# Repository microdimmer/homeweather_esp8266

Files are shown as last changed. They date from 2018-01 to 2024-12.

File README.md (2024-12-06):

# Arduino esp8266 home weather station

Clock with auto backlight, NTP time-sync, measuring CO2, humidity, temperature, atmospheric pressure and Blynk or Cayenne synchronization.

## Components

* CO2 Sensor MH-Z19
* ESP8266 (NodeMCU ESP12+ based)
* ST7920 128x64 LCD display
* Humidity/Pressure/Temperature BME280
* Photoresistor 5528 LDR
* NPN transistor P2N2222A or similar
* Buttons, resistors, wires, enclosure
### Optional
* TL431 for better display contrast adjust. (attention! need to cut JP3 on display, see photos)

## Photos:
### Version with 3D-printed case and buttons
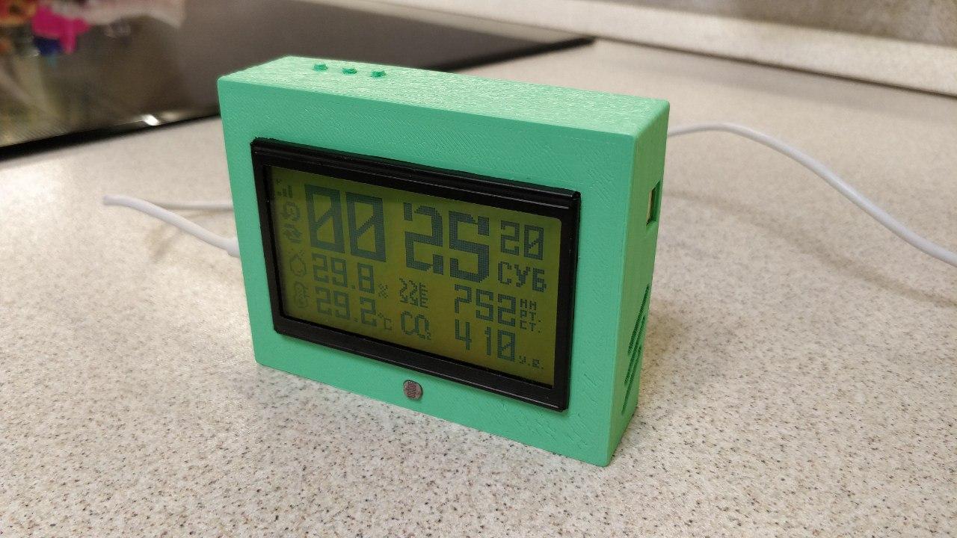
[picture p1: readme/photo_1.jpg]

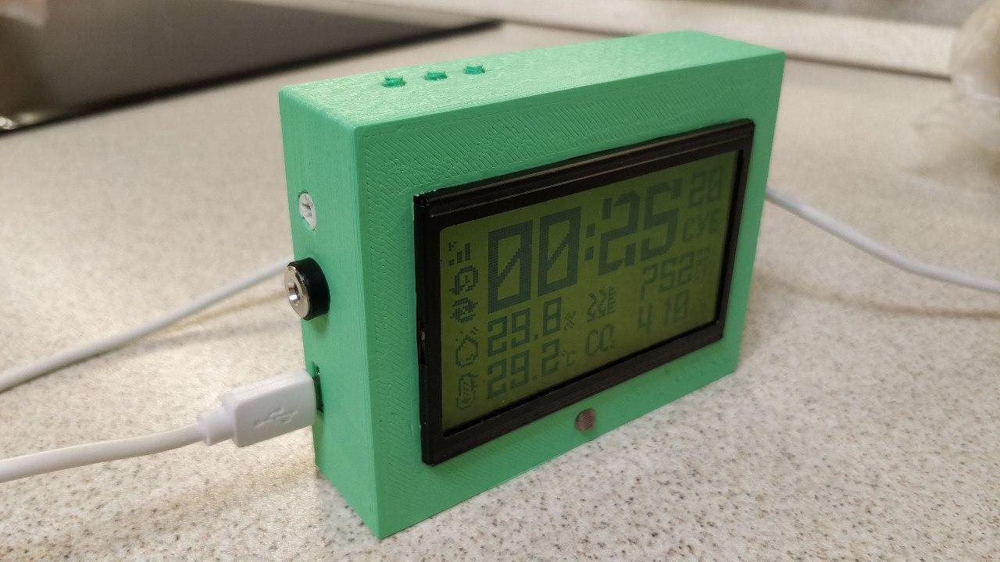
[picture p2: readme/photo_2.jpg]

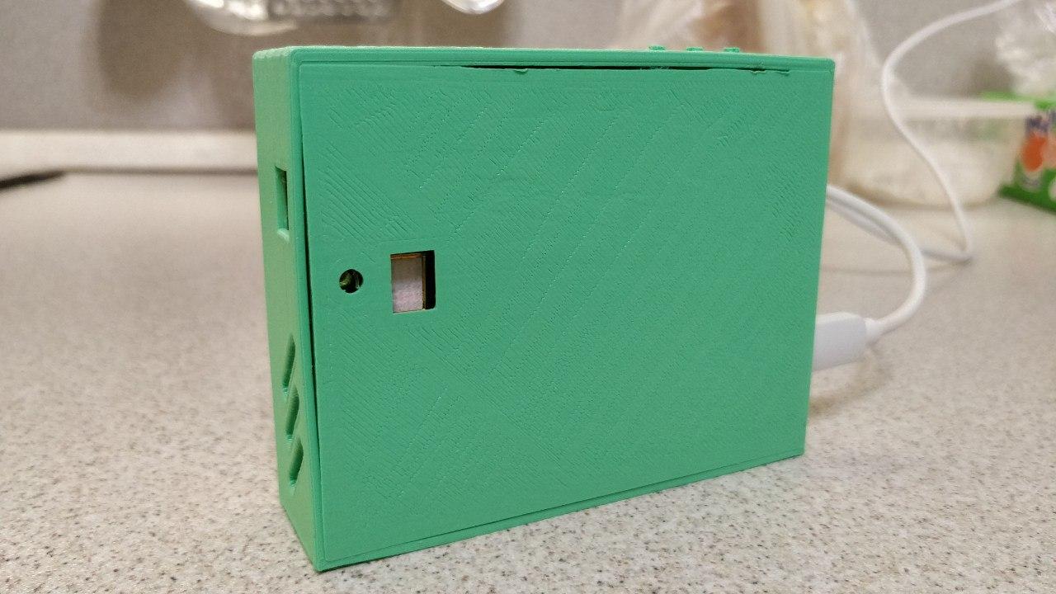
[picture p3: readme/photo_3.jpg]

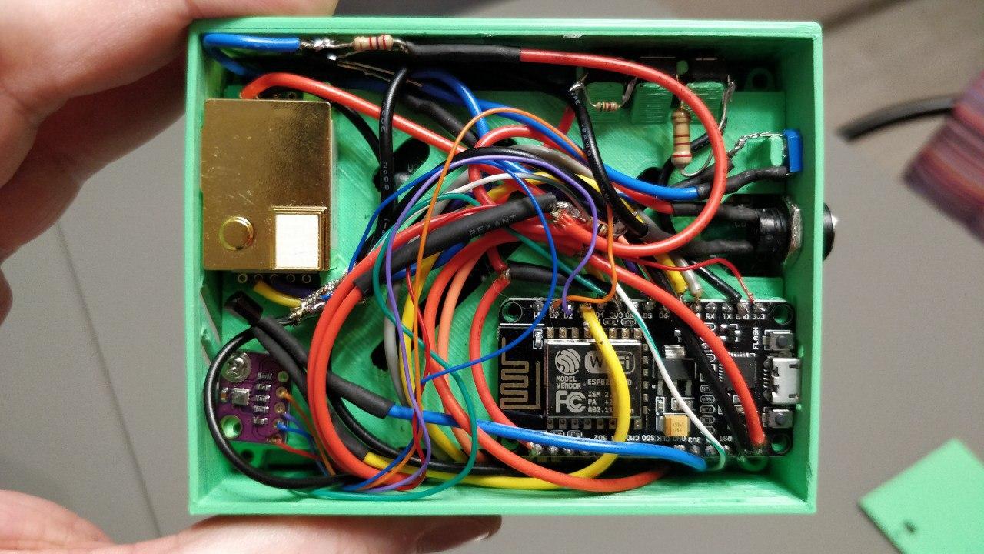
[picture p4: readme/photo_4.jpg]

### Version with purchased case and buttons
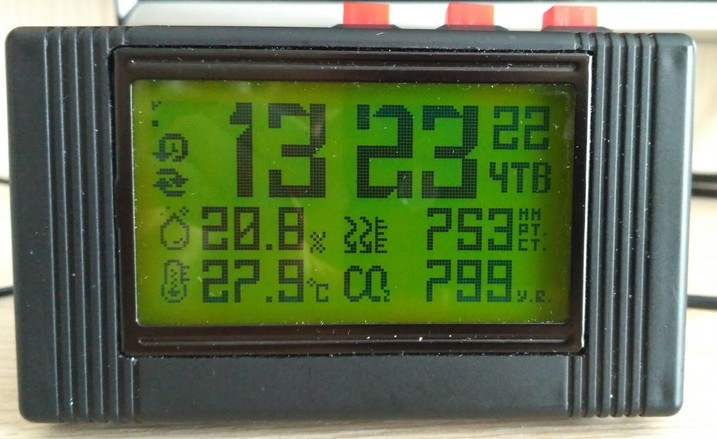
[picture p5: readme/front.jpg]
front_photo

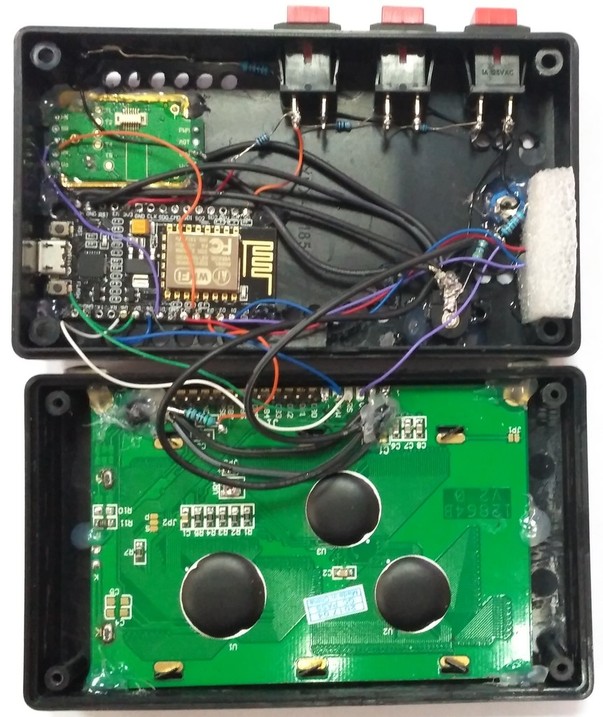
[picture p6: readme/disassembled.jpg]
disassembled_photo

### Version with 3D-printed case and buttons from [ffnull](https://github.com/ffnull)
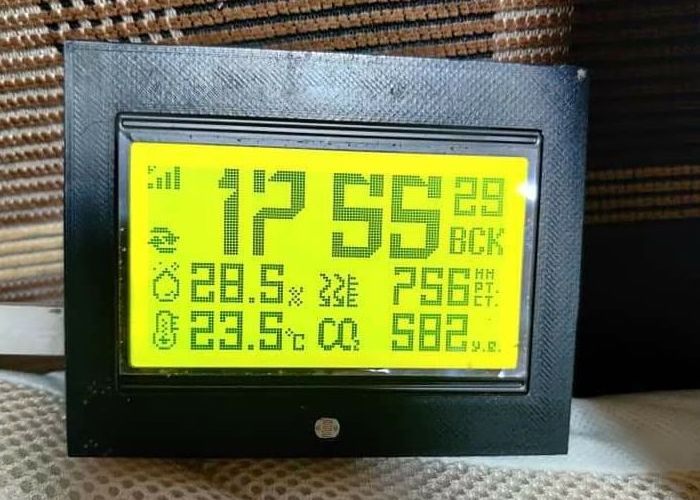
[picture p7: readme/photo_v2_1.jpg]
front_photo

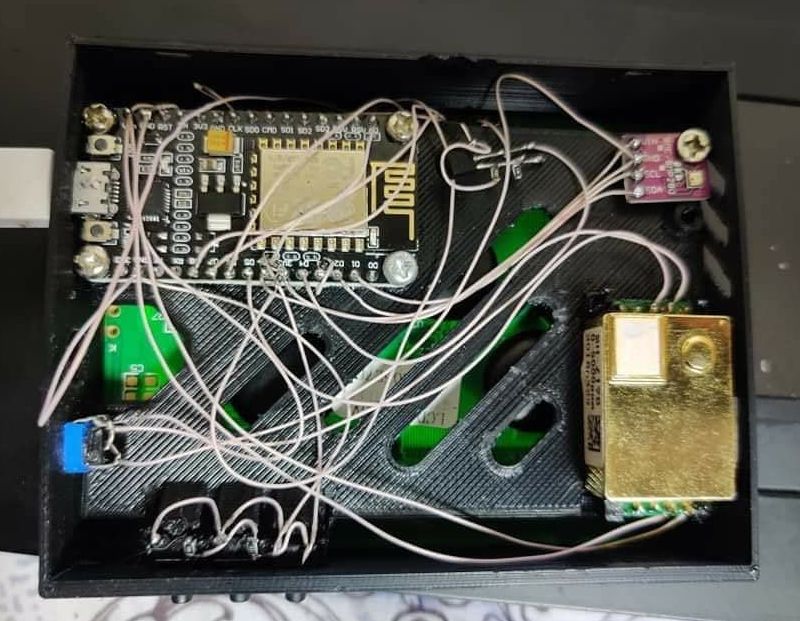
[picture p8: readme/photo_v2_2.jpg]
disassembled_photo


## 3D models
In stl folder

## Blynk and Cayenne:
[Blynk docs](http://docs.blynk.cc/)

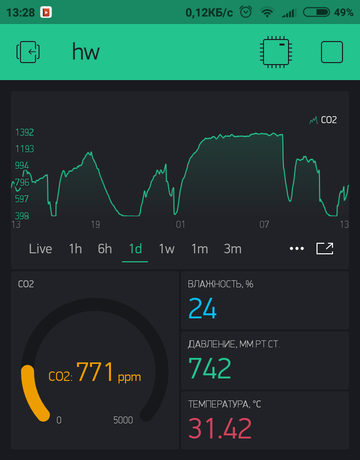
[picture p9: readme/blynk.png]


[Cayenne docs](https://mydevices.com/cayenne/features/api/)

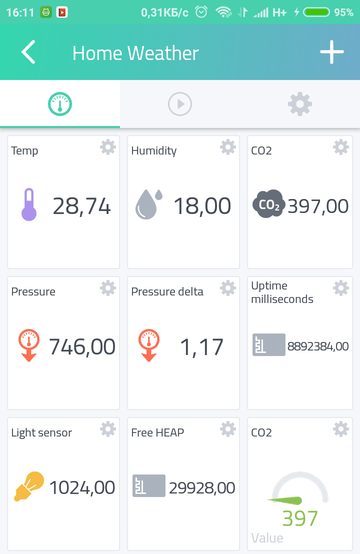
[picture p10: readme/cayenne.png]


Data is bounded to this values:
* v1 - temperature;
* v2 - humidity;
* v4 - atmospheric pressure;
* v5 - CO2 sensor MH-Z19;
* v7 - light sensor;

## Libraries

* [Arduino-esp8266](https://github.com/esp8266/Arduino)
* [Blynk](https://github.com/blynkkk/blynk-library)
* [Cayenne](https://github.com/myDevicesIoT/Cayenne-MQTT-Arduino)
* [u8g2](https://github.com/olikraus/u8g2)
* [Adafruit_BME280_Library](https://github.com/adafruit/Adafruit_BME280_Library)
* [WiFiManager](https://github.com/tzapu/WiFiManager)
* [ArduinoJson](https://github.com/bblanchon/ArduinoJson)
* [AsyncPing](https://github.com/akaJes/AsyncPing)
* [SimpleTimer](http://playground.arduino.cc/Code/SimpleTimer)
* [TimeLibrary](https://github.com/PaulStoffregen/Time)

## Wiring:
```
ST7920
RS - D8
R/W - D7
E - D6
backlight - D3

mh-z19
RX - D4
TX - D5

BME-280
SDA - D1
SCL - D2
VCC - 3V3
```

## Scheme:
### With TL431:
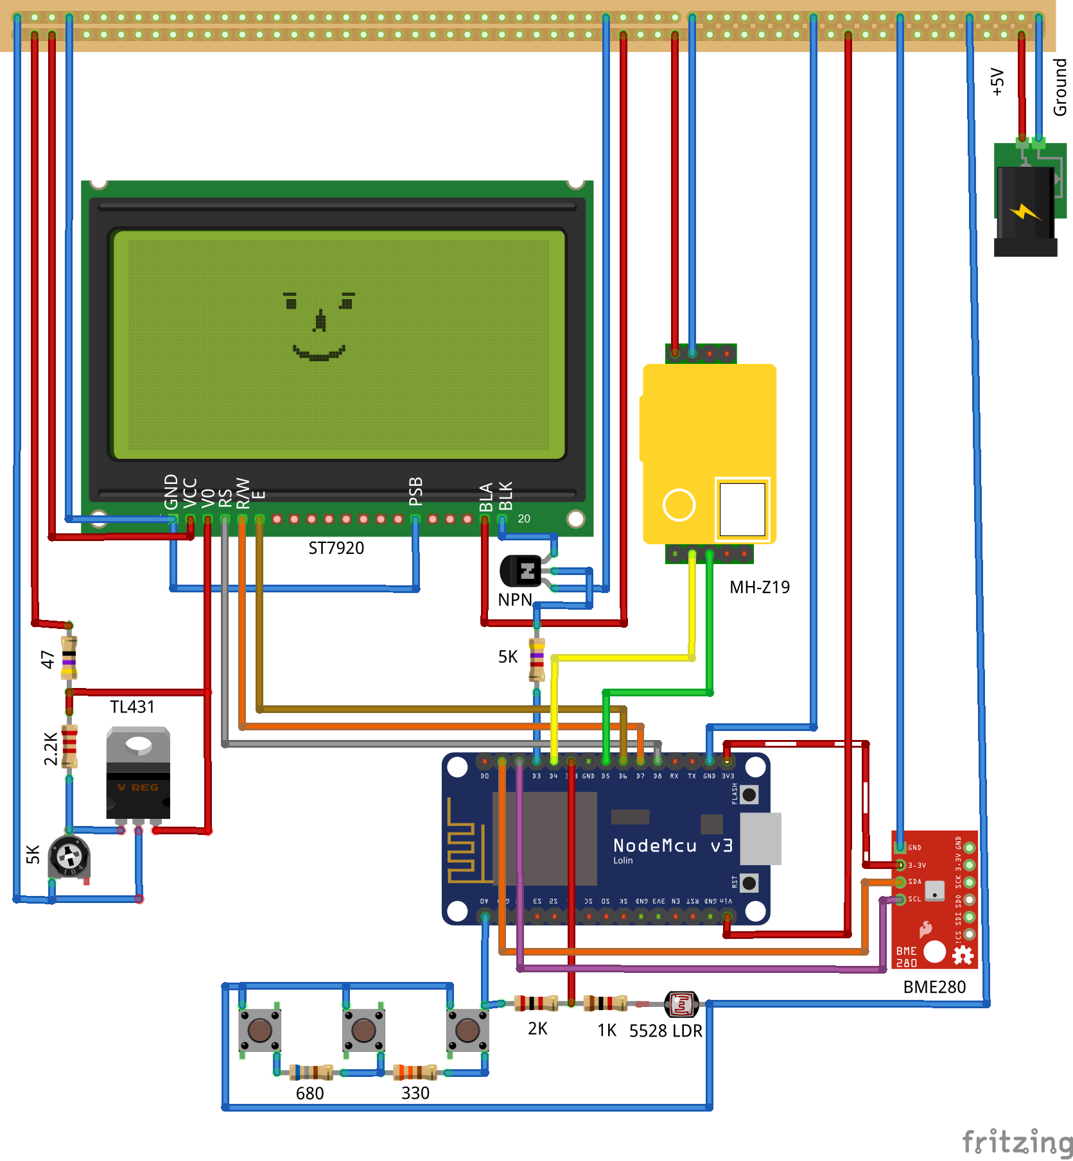
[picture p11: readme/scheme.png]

### Without TL431:
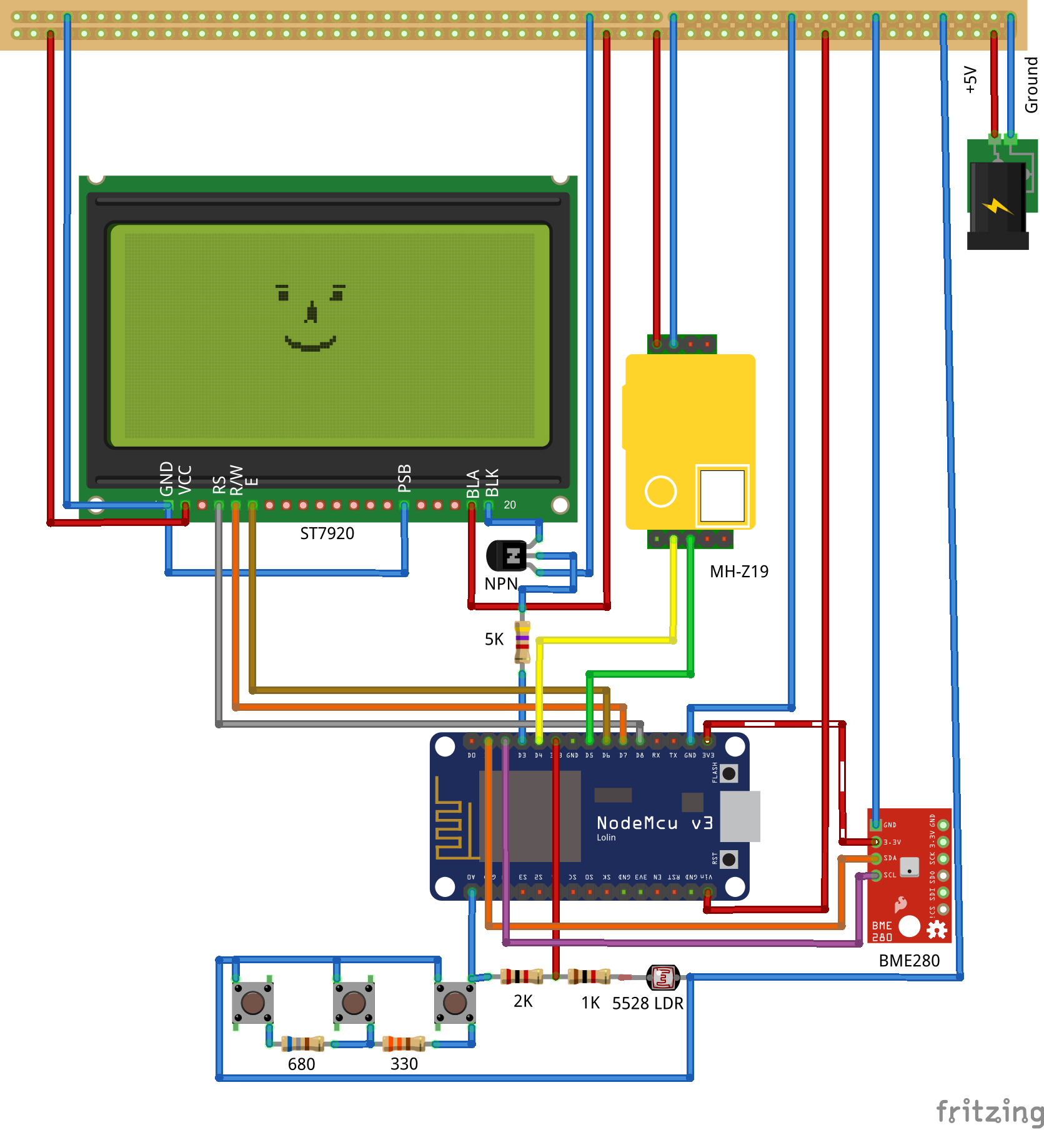
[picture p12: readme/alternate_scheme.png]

### Jumper JP3:
Attention! JP3 need to be cut to use TL431. TL431 is using for better display contrast adjust.
#### Cut:
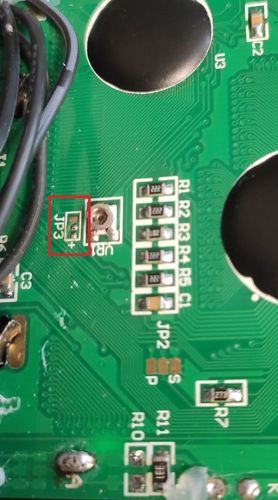
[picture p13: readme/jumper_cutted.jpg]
jumper_cut

#### Uncut:
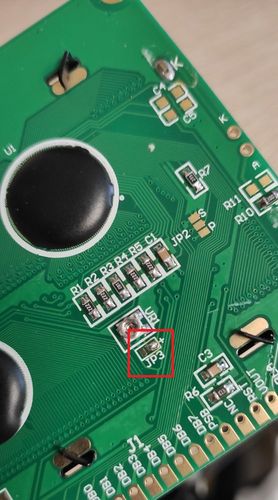
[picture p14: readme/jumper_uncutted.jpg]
jumper_uncut


## Known issues:

* Temperature measurements seems to be higher due to heat from ESP8266
* ST7920 plate need to be cut to fit enclosure
* Can't connect to my old ASUS WL-500gP V2

# Russian:
Часы с синхронизацией времени по WI-FI, функцией измерения CO2, температуры, влажности, давления. Также есть автоматическое изменение подсветки в зависимости от освещения.
Часы синхронизируются по NTP протоколу через WI-FI. Данные датчиков передаются на сервер Blynk или Cayenne.

## Компоненты

* Датчик CO2 MH-Z19
* NodeMCU v2
* ST7920 128x64 LCD-дисплей
* датчик давления/влажности/температуры BME280
* фоторезистор 5528 LDR
* NPN тразистор P2N2222A или похожий
* кнопки, резисторы, провода, корпус
### Опционально
* TL431 стабилизатор напряжения, используется для более удобной настройки контраста дисплея, можно им пренебречь. (внимание! если хотите использовать стабилизатор, нужно распаять джампер JP3 на дисплее, см. фото)

## Библиотеки

* [Arduino-esp8266](https://github.com/esp8266/Arduino)
* [Blynk](https://github.com/blynkkk/blynk-library)
* [Cayenne](https://github.com/myDevicesIoT/Cayenne-MQTT-Arduino)
* [u8g2](https://github.com/olikraus/u8g2)
* [Adafruit_BME280_Library](https://github.com/adafruit/Adafruit_BME280_Library)
* [WiFiManager](https://github.com/tzapu/WiFiManager)
* [ArduinoJson](https://github.com/bblanchon/ArduinoJson)
* [AsyncPing](https://github.com/akaJes/AsyncPing)
* [SimpleTimer](http://playground.arduino.cc/Code/SimpleTimer)
* [TimeLibrary](https://github.com/PaulStoffregen/Time)

## Подключение:
```
дисплей 12864 
RS - D8
R/W - D7
E - D6
катод подсветки - D3

датчик mh-z19
RX - D4
TX - D5

датчик BME-280
SDA - D1
SCL - D2
VCC - 3V3
```
## Известные проблемы:

* ESP8266 греется и вносит погрешность в показания температуры, пока изолировал датчик BME-280 вспененным полиэтиленом
* Пришлось немного подрезать плату дисплея ST7920 сверху, не входила по высоте
* Не удалось подключить к роутеру ASUS WL-500gP V2 (видимо нужно разбираться с типом WI-FI сети на роутере)

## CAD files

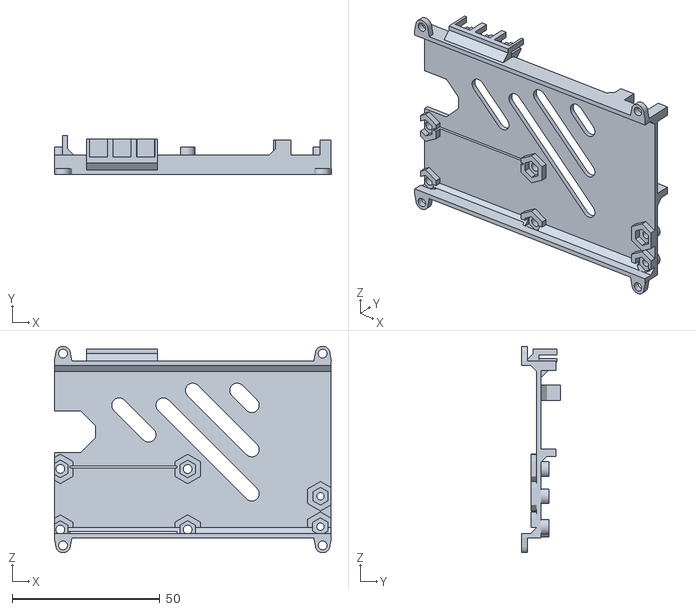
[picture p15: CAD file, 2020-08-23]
stl/mount.stl
93.9 x 13.1 x 70.0

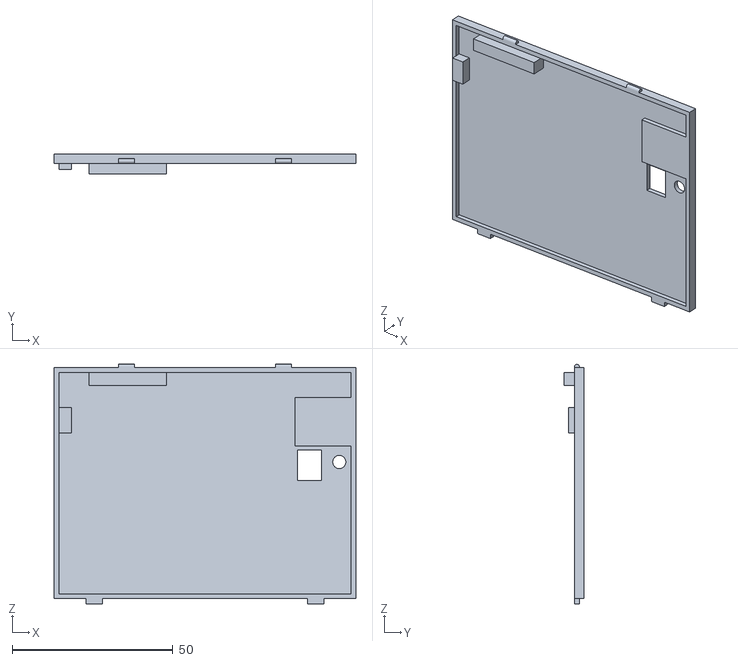
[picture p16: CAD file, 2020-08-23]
stl/back_cover.stl
93.8 x 6.30 x 74.4

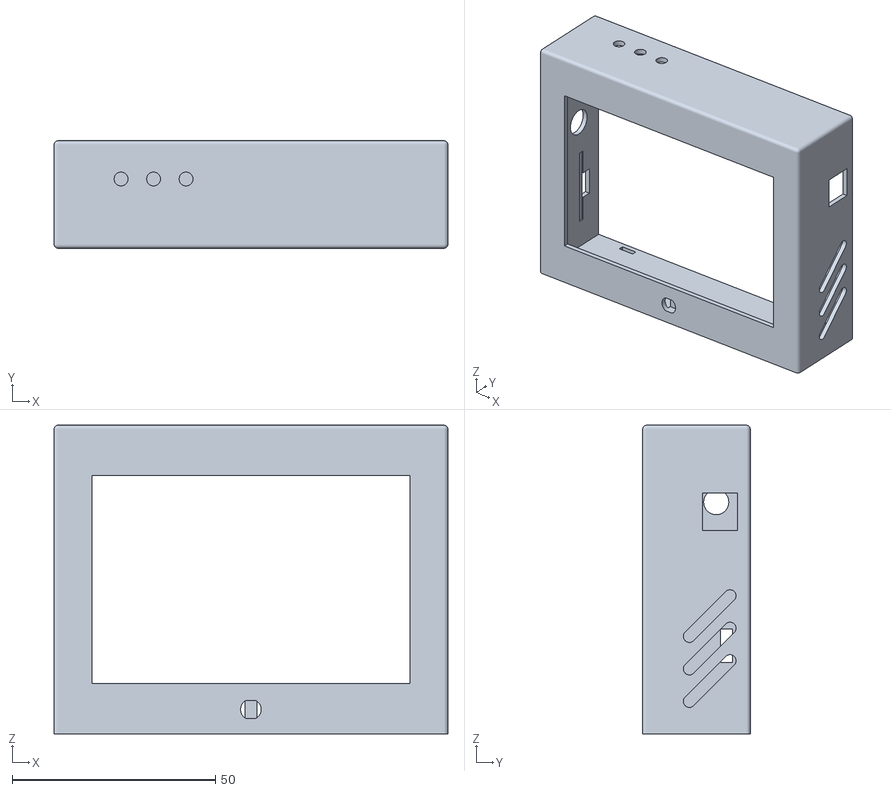
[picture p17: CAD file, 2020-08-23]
stl/case.stl
97.0 x 26.5 x 76.0

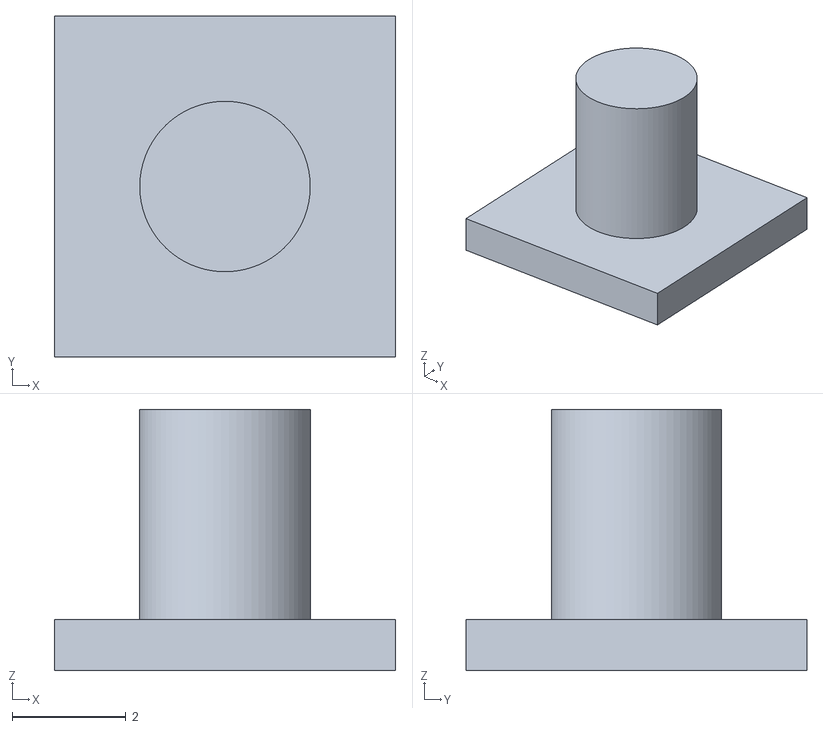
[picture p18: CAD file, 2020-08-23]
stl/pressBtn1.stl
6.00 x 6.00 x 4.60

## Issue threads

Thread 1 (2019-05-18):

TL431

sergeyvasilievich, 2019-05-18:
А для чего в схеме TL431

microdimmer, 2019-11-19:
Устанавливает постоянное напряжение на вход настройки контрастности дисплея. Так как прибор работает от почти любого блока питания на 5 В, то, из-за плавающего напряжения, при смене блока питания приходилось постоянно подстраивать контрастность дисплея.

Closed 2019-11-19.

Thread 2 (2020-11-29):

Вопросы

ffnull, 2020-11-29:
Здраствуйте!
Напечатал все детали, собрал. Но
Ни в какую не работает подсветка по датчику. В дебаге постоянно 1024.
В вариации с TL431 в схеме, похоже что ошибка - не работает от слова совсем. Временно сделал просто через резистор 5кОм
Можно исходники корпуса? Так-как были другие кнопки и датчик CO2 и пришлось колхозить.
Кнопки дают мисклики.
И главное: Спасибо за шикарный проект!

ffnull, 2020-11-29:
Еще вопрос о калибровке CO2. Возможно добавить параметр отключения автокалибровки и включение калибровки по 400ppm?

ffnull, 2020-12-20:
Автор, вы жив?

microdimmer, 2021-01-23:
Добавил 3d-модель в паку step. По второму вопросу - это для чего?

microdimmer, 2021-01-23:
Странно, но не приходят уведомления на почту, только сейчас увидел.

ffnull, 2021-01-23:
Спасибо за исходники. Пробую переписать под MQTT. Так-же добавил конденсатор на 1000Мфх16В в цепь 5В для стабилизации моргания подсветки во время включения нагрева датчика CO2. Единственное не знаю что делать с датчиком света, для автояркости. Ну и контрастность через TL431  у меня не заработала от слова совсем. Трижды перепроверил.

microdimmer, 2021-01-23:
Если что можно списаться https://t.me/microdimmer

Closed 2021-11-22.

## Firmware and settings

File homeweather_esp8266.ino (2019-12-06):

#include <FS.h>
#include <Arduino.h>
#include <SPI.h>
#include <Wire.h>
#include <SoftwareSerial.h>
#include <ESP8266WiFi.h> // Wifi Manager https://github.com/esp8266/Arduino
#include <ESP8266WebServer.h>
#include <WiFiManager.h> //https://github.com/tzapu/WiFiManager
#include <DNSServer.h>
#include <ESP8266HTTPClient.h> // HTTP requests
#include <WiFiUdp.h> //for NTP
#include <AsyncPing.h> //async pinger
#include <TimeLib.h> //timekeeping
#include <ESP8266httpUpdate.h> //OTA updates
#include <ArduinoJson.h> //https://github.com/bblanchon/ArduinoJson
#include <SimpleTimer.h> // Handy timers
#include <Adafruit_Sensor.h>
#include <Adafruit_BME280.h>
#include <U8g2lib.h>

//Preferences
// #define DEBUG //uncomment for debug messages
// #define BLYNK //uncomment for use Blynk, otherwise use Cayenne data aggregator

#ifdef BLYNK
#include <BlynkSimpleEsp8266.h> //Blynk
#else
#include <CayenneMQTTESP8266.h> //Cayenne
#endif

const uint16_t WIFI_TIMEOUT = 180;
const char * SSID = "YourHomeWeather"; // Network credentials
//String pass {"YHWBopka"}; // Wi-Fi AP password
// GPIO Defines
const uint8_t I2C_SDA = 5; // D1, SDA pin, GPIO5 for BME280
const uint8_t I2C_SCL = 4; // D2, SCL pin, GPIO4 for BME280
const uint8_t PWM_PIN = 0; //D3, GPIO0, for ST7920
const uint8_t SCLK_PIN = 12; // D6, E pin, GPIO12, for ST7920 acts like CLK (clock) input pin
const uint8_t RW_PIN = 13; // D7, R/W pin, GPIO13, for ST7920 acts like DATA pin
const uint8_t RS_PIN = 15; // D8, RS pin, GPIO15, for ST7920 acts like CS (Chip Select) pin
const uint8_t TX_PIN = 2; //D4, RX pin, GPIO2, for mz-h19
const uint8_t RX_PIN = 14; //D5, TX pin, GPIO14, for mz-h19

//display ST7920
U8G2_ST7920_128X64_F_SW_SPI u8g2(U8G2_R0,/*display-clock E,SCLK;esp-GPIO12,D6*/SCLK_PIN,/*display-data R/W;esp-GPIO13,D7*/RW_PIN,/*display-RS;esp-GPIO15,D8*/RS_PIN);
// Humidity/Temperature/Pressure/CO2
Adafruit_BME280 bme;
SoftwareSerial swSer(RX_PIN, TX_PIN);// CO2 SERIAL
//SoftwareSerial swSer(RX_PIN, TX_PIN, false, 256);// CO2 SERIAL
byte cmd[9] = {0xFF, 0x01, 0x86, 0x00, 0x00, 0x00, 0x00, 0x00, 0x79};
unsigned char response[7];
#ifdef BLYNK
// Blynk token
char blynk_token[33] {"7ca0a9293079453499aa5453883510cf"};
char blynk_server[64] {"blynk-cloud.com"};
const uint16_t blynk_port {8442};
#else
// Cyenne credentials
char cayenne_username[] = "edc8aad0-d07d-11e7-8123-07faebe02555";
char cayenne_password[] = "3924eb177886b6280ee0b13b0045d2a5a7e66216";
char cayenne_clientID[] = "2dd4dd50-479e-11e8-bf56-db14f0c2b326";
#endif
// Device Id
char device_id[17] = "Home Weather";
const char fw_ver[17] = "0.1.22";
// Handy timer
SimpleTimer timer;
// Setup Wifi connection
WiFiManager wifiManager;

//sensors data
int16_t t { -100};
int16_t p { -1};
int16_t h { -1};
int co2 {0};
float tf {0};
float pf {0};
float hf {0};
uint16_t light;
uint16_t adc_data;
uint32_t uptime = 0;
//buttons
const uint8_t NUM_KEYS = 3;
int adc_key_val[NUM_KEYS] = {100, 200, 360};
uint32_t lastDebounceTime = 0;
uint16_t debounceTime = 250;
uint32_t lastIdleTimeMenu = 0;
uint32_t idleTimeMenu = 180000; // menu idle time 3 min
// Math data for pressure calculating, see http://bit.ly/1EXW1I9 http://bit.ly/1DIbvyj
const uint8_t P_LEN = 4;
float p_array[P_LEN];
float delta;
//flags
volatile bool connectedInetFlag = false; //flag if connected
bool timeSyncFlag = false;
bool cloudSyncFlag = false;
#ifndef BLYNK
bool CayenneConnectedFlag = false;
#endif
bool shouldSaveConfig = false; //flag for saving data if connectio estalished
//menu
bool timeSetFlag = false; //TODO del flags
bool timeSetMinFlag = false;
bool timeSetHourFlag = false;
bool timeSetTimeZoneFlag = false;
bool timeSetDayFlag = false;
bool timeSetMonthFlag = false;
bool timeSetYearFlag = false;
bool backlightSetFlag = false;
bool backlightSetLEDFlag = false;
bool backlightSetMinFlag = false;
bool backlightSetMaxFlag = false;
bool backlightSetThresoldFlag = false;

bool menuFlag = false;
int8_t curMenuItem = 3;
int8_t menuItemsCount = 4;

int32_t wifiRSSI = 0;

const uint16_t pwm_light[14] = {0, 0, 2, 4, 8, 16, 32, 64, 96, 128, 192, 256, 320, 384};
int8_t light_mode = 0;
int8_t light_auto_min = 2; //default min backlight
int8_t light_auto_max = 11; //default max backlight
uint16_t light_auto_thresold = 1023; //default thresold
uint32_t lightLastHysteresisTimeMin = 0;
uint32_t lightLastHysteresisTimeMax = 0;
uint16_t lightHysteresisTime = 2500; //2.5 secs hysteresis for light sensor

AsyncPing aping;

WiFiUDP Udp;
const char* ntpServerName = "0.ru.pool.ntp.org"; //NTP server (ntp2.stratum2.ru,ntp1.vniiftri.ru)
IPAddress ntpServerIP;
#ifdef BLYNK
IPAddress pingServerIP(139, 59, 206, 133); //blynk serv for ping
#endif
unsigned int localPort = 4567;  // local port to listen for UDP packets
const int NTP_PACKET_SIZE = 48; // NTP time is in the first 48 bytes of message
byte packetBuffer[NTP_PACKET_SIZE]; //buffer to hold incoming & outgoing packets
const uint16_t timeZonesArr[11] = {2, 3, 4, 5, 6, 7, 8, 9, 10, 11, 12};
int8_t timeZone = 3;         // default timezone UTC +5

String timestring = "";//TODO

#include "graphics.h"

#ifdef DEBUG
#define PRINTLNF(s)   { Serial.println(F(s)); }
#define PRINTLN(s,v)  { Serial.print(F(s)); Serial.println(v); }
#else
#define PRINTLNF(s)
#define PRINTLN(s,v)
#endif


time_t getNtpTime() {
  while (Udp.parsePacket() > 0) ; // discard any previously received packets
  PRINTLNF("Transmit NTP Request");
  #ifdef BLYNK
  ntpServerIP = pingServerIP;
  #else
  WiFi.hostByName(ntpServerName, ntpServerIP); //get IP address
  #endif
  sendNTPpacket(ntpServerIP);
  uint32_t beginWait = millis();
  while (millis() - beginWait < 1500) {
    int size = Udp.parsePacket();
    if (size >= NTP_PACKET_SIZE) {
      PRINTLNF("Receive NTP Response");
      Udp.read(packetBuffer, NTP_PACKET_SIZE);  // read packet into the buffer
      unsigned long secsSince1900;
      // convert four bytes starting at location 40 to a long integer
      secsSince1900 =  (unsigned long)packetBuffer[40] << 24;
      secsSince1900 |= (unsigned long)packetBuffer[41] << 16;
      secsSince1900 |= (unsigned long)packetBuffer[42] << 8;
      secsSince1900 |= (unsigned long)packetBuffer[43];
      timeSyncFlag = 1;
      return secsSince1900 - 2208988800UL + timeZonesArr[timeZone] * SECS_PER_HOUR;
    }
  }
  PRINTLNF("No NTP Response :-(");
  timeSyncFlag = 0;
  return 0; // return 0 if unable to get the time
}

void sendNTPpacket(IPAddress &address) { // send an NTP request to the time server at the given address
  // set all bytes in the buffer to 0
  memset(packetBuffer, 0, NTP_PACKET_SIZE);
  // Initialize values needed to form NTP request
  packetBuffer[0] = 0b11100011;   // LI, Version, Mode
  packetBuffer[1] = 0;     // Stratum, or type of clock
  packetBuffer[2] = 6;     // Polling Interval
  packetBuffer[3] = 0xEC;  // Peer Clock Precision
  // 8 bytes of zero for Root Delay & Root Dispersion
  packetBuffer[12]  = 49;
  packetBuffer[13]  = 0x4E;
  packetBuffer[14]  = 49;
  packetBuffer[15]  = 52;
  // all NTP fields have been given values, now
  // you can send a packet requesting a timestamp:
  Udp.beginPacket(address, 123); //NTP requests are to port 123
  Udp.write(packetBuffer, NTP_PACKET_SIZE);
  Udp.endPacket();
}

void syncTime() {
  setTime(getNtpTime());
  #ifdef DEBUG
    timeStatus_t t_status = timeStatus();
    if (t_status == timeNotSet) {
      PRINTLNF("Time never been synced");
    }  
    else if (t_status == timeNeedsSync) {
      PRINTLNF("Time is need to sync");
    }  
    else if (t_status == timeSet) {
      PRINTLNF("Time is synced");
    }
  #endif    
}

String weekdayRus(byte weekday) {
  switch (weekday) {
    case 2:
      return "PON";
    case 3:
      return "VTR";
    case 4:
      return "SRD";
    case 5:
      return "CTV";
    case 6:
      return "PTN";
    case 7:
      return "SYB";
    case 1:
      return "VSK";
  }
  return "0";
}

void drawSignalQuality(uint8_t x, uint8_t y) {
  if (!connectedInetFlag) {
    u8g2.drawLine(x, y, x + 2, y + 2);
    u8g2.drawLine(x, y + 2, x + 2, y);
  }
  else {
    u8g2.drawLine(x, y + 2, x + 2, y);
    u8g2.drawLine(x, y, x, y + 2);
  }
  y = y + 6;
  if (wifiRSSI >= -90)
    u8g2.drawFrame(x, y, x + 2, y - 4);
  if (wifiRSSI >= -85)
    u8g2.drawFrame(x + 3, y - 2, x + 2, y - 2);
  if (wifiRSSI >= -75)
    u8g2.drawFrame(x + 6, y - 4, x + 2, y);
  if (wifiRSSI >= -65)
    u8g2.drawFrame(x + 9, y - 6, x + 2, y + 2);
}

const char *GetStringLine(uint8_t line_idx, const char *str ) { //Assumes strings, separated by '\n' in "str". Returns the string at index "line_idx". First strng has line_idx = 0
  char e;
  uint8_t line_cnt = 1;

  if ( line_idx == 0 )
    return str;

  for (;;)
  {
    e = *str;
    if ( e == '\0' )
      break;
    str++;
    if ( e == '\n' )
    {
      if ( line_cnt == line_idx )
        return str;
      line_cnt++;
    }
  }
  return NULL;  /* line not found */
}

const char* printDigits(uint16_t digits, bool blinking = false, bool leadingZero = true) { //prints preceding colon and leading 0, blinking
  timestring = String(digits);
  if (blinking && ((millis() / 500 % 2) == 0))
    return "";
  if (digits < 10 && leadingZero)
    timestring = "0" + String(digits);

  return timestring.c_str();
}

void drawMainScreen() {
  u8g2.clearBuffer();
  u8g2.setFont(custom_font_14);
  if (timeSetFlag) {
    u8g2.drawStr(15, 14, printDigits(hour(), timeSetHourFlag));
    u8g2.drawStr(35, 14, ":");
    u8g2.drawStr(39, 14, printDigits(minute(), timeSetMinFlag));
    u8g2.setFont(custom_font_7);
    u8g2.drawStr(62, 10, "utc");
    u8g2.setFont(custom_font_14);
    u8g2.drawStr(76, 14, "+");
    u8g2.drawStr(84, 14, printDigits(timeZonesArr[timeZone], timeSetTimeZoneFlag, false));
    u8g2.drawStr(15, 30, printDigits(day(), timeSetDayFlag));
    u8g2.drawStr(35, 30, ".");
    u8g2.drawStr(39, 30, printDigits(month(), timeSetMonthFlag));
    u8g2.drawStr(59, 30, ".");
    u8g2.drawStr(64, 30, printDigits(year(), timeSetYearFlag));
  }
  else if (backlightSetFlag) {
    u8g2.setFont(custom_font_7);
    u8g2.drawStr(17, 14, "led:");
    if (light_mode == 0) {
      u8g2.drawStr(62, 14, "min:");
      u8g2.drawStr(13, 24, "thre");
      u8g2.drawStr(13, 30, "sold:");
      u8g2.drawStr(62, 30, "max:");
      u8g2.setFont(u8g2_font_7x13_mf);
      u8g2.drawStr(32, 14, "auto");
      u8g2.setFont(custom_font_14);
      u8g2.drawStr(32, 30, printDigits(light_auto_thresold / 10, backlightSetThresoldFlag, false));
      u8g2.drawStr(77, 14, printDigits(light_auto_min, backlightSetMinFlag, false));
      u8g2.drawStr(77, 30, printDigits(light_auto_max, backlightSetMaxFlag, false));
    }
    else if (light_mode == 1) {
      u8g2.setFont(u8g2_font_7x13_mf);
      u8g2.drawStr(32, 14, "off");
    }
    else {
      u8g2.setFont(custom_font_14);
      u8g2.drawStr(32, 14, printDigits(light_mode, backlightSetFlag, false));
    }
  }
  else { //draw time
    u8g2.setFont(custom_font30);
    u8g2.drawStr(15, 30 , printDigits(hour()));
    if ((millis() / 1000) % 2) u8g2.drawStr(57, 30 , ":");
    u8g2.drawStr(64, 30 , printDigits(minute()));
  }

  if (WiFi.status() == WL_CONNECTED) {
    drawSignalQuality(0, 0);
  }
  if (timeSyncFlag) {
    u8g2.drawXBMP(0, 10, 11, 9, clock_bitmap);
  }
  if (cloudSyncFlag) {
    u8g2.drawXBMP(0, 21, 11, 9, sync_bitmap);
  }

  u8g2.setFont(rus_font);
  u8g2.drawStr(107, 28, weekdayRus(weekday()).c_str());

  u8g2.setFont(custom_font_14);
  u8g2.drawStr(108, 14 , printDigits(day()));

  //CO2
  String co2String = String(co2);
  u8g2.drawXBMP(60, 52, 15, 12, co_bitmap);
  u8g2.drawStr(117 - (co2String.length() * 10), 64 , co2String.c_str());
  // Temp, Humidity, Pressure
  String tfString = String(tf, 1);
  u8g2.drawXBMP(2, 50, 10, 14, temp_bitmap);
  u8g2.drawStr(55 - (tfString.length() * 10), 64, tfString.c_str());

  String hfString = String(hf, 1);
  u8g2.drawXBMP(2, 33, 10, 14, humid_bitmap);
  u8g2.drawStr(55 - (hfString.length() * 10), 47, hfString.c_str());

  u8g2.drawXBMP(60, 36, 14, 12, p_bitmap);

  if (delta > 2) {
    u8g2.drawGlyph(76, 47, 30); //big arrow up
  }
  else if (delta > 1) {
    u8g2.drawGlyph(76, 47, 28); //small arrow up
  }
  else if (delta < -2) {
    u8g2.drawGlyph(76, 47, 31); //big arrow down
  }
  else if (delta < -1) {
    u8g2.drawGlyph(76, 47, 29); //small arrow down
  }

  u8g2.drawStr(87, 47, String(p).c_str());

  u8g2.setFont(custom_font_7);
  u8g2.drawGlyph(48, 64, 0xb0); //degree sign
  u8g2.drawStr(51, 64, "C");
  u8g2.drawGlyph(49, 48, 0x25); //percent
  u8g2.drawStr(117, 64 , "y.e.");
  u8g2.drawStr(117, 37 , "mm");
  u8g2.drawStr(117, 42 , "pt.");
  u8g2.drawStr(117, 47 , "ct.");

  u8g2.sendBuffer();
}

void drawMenu(const char *title, uint8_t start_pos, const char *line) {
  if ((millis() - lastIdleTimeMenu) > idleTimeMenu) {
    menuFlag = false;
    return;
  }

  u8g2.clearBuffer();
  byte x {0}; byte y {0};

  u8g2.setFont(u8g2_font_7x13_mf);

  x = (128 - u8g2.getStrWidth(title)) / 2;
  y = u8g2.getAscent() - u8g2.getDescent() - 2;
  u8g2.drawStr(x, y, title);
  y++;
  u8g2.drawHLine(0, y, 127);

  for (byte  i = 0; i < menuItemsCount; i++) {
    const char *msg = GetStringLine(i, line);
    if (i == start_pos) {
      u8g2.drawBox(0, y + 2, 127, u8g2.getAscent() - u8g2.getDescent() + 2);
      u8g2.setDrawColor(0);
    }
    else
      u8g2.setDrawColor(1);
    x = (128 - u8g2.getStrWidth(msg)) / 2;
    y = y + 2 + u8g2.getAscent() - u8g2.getDescent();
    u8g2.drawStr(x, y, msg);
  }
  u8g2.setDrawColor(1);
  u8g2.sendBuffer();
}

void drawBoot(String msg = "loading...") {
  u8g2.clearBuffer();
  u8g2.setFont(u8g2_font_7x13_mf);
  byte x {0}; byte y {0};
  x = (128 - u8g2.getStrWidth(msg.c_str())) / 2;
  y = 32 + u8g2.getAscent() / 2;
  u8g2.drawStr(x, y, msg.c_str());
  u8g2.sendBuffer();
}

void drawConnectionDetails(String ssid, String mins, String url) {
  String msg {""};
  u8g2.clearBuffer();
  byte x {0}; byte y {0};

  msg = "Connect to WiFi:";
  u8g2.setFont(u8g2_font_7x13_mf);
  x = (128 - u8g2.getStrWidth(msg.c_str())) / 2;
  y = u8g2.getAscent() - u8g2.getDescent();
  u8g2.drawStr(x, y, msg.c_str());

  x = (128 - u8g2.getStrWidth(msg.c_str())) / 2;
  y = y + 1 + u8g2.getAscent() - u8g2.getDescent();
  u8g2.drawStr(x, y, ssid.c_str());

  msg = "waiting for " + mins;
  x = (128 - u8g2.getStrWidth(msg.c_str())) / 2;
  y = y + 1 + u8g2.getAscent() - u8g2.getDescent();
  u8g2.drawStr(x, y, msg.c_str());

  msg = "Open browser:";
  x = (128 - u8g2.getStrWidth(msg.c_str())) / 2;
  y = y + 1 + u8g2.getAscent() - u8g2.getDescent();
  u8g2.drawStr(x, y, msg.c_str());

  x = (128 - u8g2.getStrWidth(url.c_str())) / 2;
  y = y + 1 + u8g2.getAscent() - u8g2.getDescent();
  u8g2.drawStr(x, y, url.c_str());

  u8g2.sendBuffer();
}

void saveConfigCallback() { //callback notifying when need to save config
  PRINTLNF("Should save config");
  shouldSaveConfig = true;
}

void factoryReset() {
  PRINTLNF("Resetting to factory settings");
  wifiManager.resetSettings();
  SPIFFS.format();
  ESP.reset();
}

void readCO2() {
  bool header_found {false};

  swSer.write(cmd, 9);
  memset(response, 0, 7);

  // Looking for packet start
  while (swSer.available() && (!header_found)) {
    if (swSer.read() == 0xff ) {
      if (swSer.read() == 0x86 ) header_found = true;
    }
  }

  if (header_found) {
    swSer.readBytes(response, 7);

    byte crc = 0x86;
    for (byte i = 0; i < 6; i++) {
      crc += response[i];
    }
    crc = 0xff - crc;
    crc++;

    if ( !(response[6] == crc) ) {
      PRINTLN("CO2: CRC error: ", String(crc) + " / " + String(response[6]));
    } 
    else {
      unsigned int responseHigh = (unsigned int) response[0];
      unsigned int responseLow = (unsigned int) response[1];
      unsigned int ppm = (256 * responseHigh) + responseLow;
      co2 = ppm;
      PRINTLN("CO2:",co2);
    }
  } else {
    PRINTLNF("CO2: Header not found");
  }
}

void readMeasurements() {
  tf = bme.readTemperature(); //Temperature
  t = static_cast<int>(tf);
  hf = bme.readHumidity(); //Humidity
  h = static_cast<int>(hf);
  pf = bme.readPressure() * 760.0 / 101325; //Pressure (in mmHg)
  p = static_cast<int>(floor(pf + 0.5));
  readCO2();// CO2
  if (WiFi.status() == WL_CONNECTED) {
    wifiRSSI = WiFi.RSSI(); //WiFi signal strength (RSSI)
    PRINTLN("Wi-Fi RSSI: ", String(wifiRSSI) + "dBm"); //Write to debug console
  }  
  if (adc_data > 370)
    light = adc_data;
  uptime+=10;  //uptime
  
  PRINTLN("H: ", String(hf) + "%"); //Write to debug console
  PRINTLN("T: ", String(tf) + "C");
  PRINTLN("Pf: ", String(pf, 1) + "mmHg");
  PRINTLN("CO2: ", String(co2) + "ppm");
  PRINTLN("Light sensor: ", String(light));
  PRINTLN("Free Heap: ",ESP.getFreeHeap());
}

void read_p_arr() {
  for (uint8_t i = 0; i < P_LEN - 1; i++) {
    p_array[i] = p_array[i + 1];
  }
  p_array[P_LEN - 1] = bme.readPressure() * 760.0 / 101325;

  float sumX = 0, sumY = 0, sumX2 = 0, sumXY = 0;
  for (uint8_t i = 0; i < P_LEN; i++) {
    sumX += i + 1;
    sumY += p_array[i];
    sumX2 += (i + 1) * (i + 1);
    sumXY += (i + 1) * p_array[i];
  }
  float a = 0;
  a = sumX * sumY;
  a = a - P_LEN * sumXY;
  a = a / (sumX * sumX - P_LEN * sumX2);
  delta = a * 3 ; // delta of changing pressure for 3 hours
  PRINTLN("Pressure delta ", delta);
}

void sendMeasurements() {   // send to server
  if (connectedInetFlag) {
    if (timeStatus() == timeNotSet)
      syncTime();
  #ifdef BLYNK    
    if (connectBlynk()) {
      Blynk.virtualWrite(V1, tf);
      Blynk.virtualWrite(V2, h);
      Blynk.virtualWrite(V4, p);
      Blynk.virtualWrite(V5, co2);
      Blynk.virtualWrite(V6, delta); //pressure delta
      Blynk.virtualWrite(V7, light); //light sensor
      Blynk.virtualWrite(V8, millis());
      Blynk.virtualWrite(V9, ESP.getFreeHeap());
      Blynk.run();
  #else    
    if (CayenneConnectedFlag) {
      Cayenne.virtualWrite(1, tf);
      Cayenne.virtualWrite(2, hf);
      Cayenne.virtualWrite(4, pf);
      Cayenne.virtualWrite(5, co2);
      Cayenne.virtualWrite(6, delta); //pressure delta
      Cayenne.virtualWrite(7, light); //light sensor
      Cayenne.virtualWrite(8, numberOfHours(uptime)); //uptime hours
      Cayenne.virtualWrite(9, ESP.getFreeHeap());
      Cayenne.loop();
  #endif  
      cloudSyncFlag = 1;
      PRINTLNF("Send to data server");
    }
    else {
      cloudSyncFlag = 0;
      PRINTLNF("Send data to server fails!");
    }
  }
  else
    cloudSyncFlag = 0;
}

#ifdef BLYNK 
bool connectBlynk() {
  if (!Blynk.connected())
    return Blynk.connect();
  return true;
}
#endif

void asyncPing() {
  if (WiFi.status() == WL_CONNECTED)
    aping.begin(ntpServerIP, 5, 1500);
  else
    connectedInetFlag = false;  
}

bool loadConfig() {
  PRINTLNF("Load config...");
  File configFile = SPIFFS.open("/config.json", "r");
  if (!configFile) {
    PRINTLNF("Failed to open config file");
    return false;
  }

  size_t size = configFile.size();
  if (size > 1024) {
    PRINTLNF("Config file size is too large");
    return false;
  }

  std::unique_ptr<char[]> buf(new char[size]);

  configFile.readBytes(buf.get(), size);

  StaticJsonDocument<200> jsonBuffer;
//  JsonObject json = jsonBuffer.parseObject(buf.get());
  auto error = deserializeJson(jsonBuffer, buf.get());
  if (error) {
    PRINTLNF("Failed to parse config file");
    return false;
  }

  timeZone = jsonBuffer["timeZone"];  // load parameters
  light_auto_thresold = jsonBuffer["light_auto_thresold"];
  light_auto_min = jsonBuffer["light_auto_min"];
  light_auto_max = jsonBuffer["light_auto_max"];
  return true;
}

bool writeConfig() {
  PRINTLNF("Load config...");
  File configFile = SPIFFS.open("/config.json", "w");
  if (!configFile)
    return false;

  DynamicJsonDocument jsonBuffer(1024);
//  JsonObject json = jsonBuffer.createObject();
  jsonBuffer["timeZone"] = timeZone;
  jsonBuffer["light_auto_thresold"] = light_auto_thresold;
  jsonBuffer["light_auto_min"] = light_auto_min;
  jsonBuffer["light_auto_max"] = light_auto_max;

//  jsonBuffer.printTo(configFile);
  serializeJson(jsonBuffer, configFile);
  configFile.close();
  return true;
}

bool loadConfigWiFI() {
  PRINTLNF("Load config...");
  File configFile = SPIFFS.open("/configwifi.json", "r");
  if (!configFile) {
    PRINTLNF("Failed to open config file");
    return false;
  }

  size_t size = configFile.size();
  if (size > 1024) {
    PRINTLNF("Config file size is too large");
    return false;
  }

  // Allocate a buffer to store contents of the file.
  std::unique_ptr<char[]> buf(new char[size]);

  // We don't use String here because ArduinoJson library requires the input
  // buffer to be mutable. If you don't use ArduinoJson, you may as well
  // use configFile.readString instead.
  configFile.readBytes(buf.get(), size);

  StaticJsonDocument<200> jsonBuffer;
//  JsonObject json = jsonBuffer.parseObject(buf.get());
  auto error = deserializeJson(jsonBuffer, buf.get());
  if (error) {
    PRINTLNF("Failed to parse config file");
    return false;
  }
  // Save parameters
  #ifdef BLYNK 
  strcpy(device_id, jsonBuffer["device_id"]);
  strcpy(blynk_server, jsonBuffer["blynk_server"]);
  strcpy(blynk_token, jsonBuffer["blynk_token"]);
  #else
  strcpy(cayenne_username, jsonBuffer["cayenne_username"]);
  strcpy(cayenne_password, jsonBuffer["cayenne_password"]);
  strcpy(cayenne_clientID, jsonBuffer["cayenne_clientID"]);
  #endif
  return true;
}
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
void loop() {
  timer.run();

  if (menuFlag)
    drawMenu("MAIN MENU", curMenuItem, "Time set\nBacklight set\nErase data & reset\nExit");
  else
    drawMainScreen();

  adc_data = analogRead(A0);
  adcDecode();

  // if (connectedInetFlag)
    // Blynk.run();
}

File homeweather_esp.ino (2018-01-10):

#include <FS.h>
#include <Arduino.h>
#include <ESP8266WiFi.h>          //https://github.com/esp8266/Arduino
// Wifi Manager
#include <DNSServer.h>
#include <ESP8266WebServer.h>
#include <WiFiManager.h>         //https://github.com/tzapu/WiFiManager
// HTTP requests
#include <ESP8266HTTPClient.h>
//for NTP
#include <WiFiUdp.h>
//Time lib
#include <TimeLib.h>

// OTA updates
#include <ESP8266httpUpdate.h>
// Blynk
#include <BlynkSimpleEsp8266.h>
// Debounce
#include <Bounce2.h> //https://github.com/thomasfredericks/Bounce2
// JSON
#include <ArduinoJson.h> //https://github.com/bblanchon/ArduinoJson

// GPIO Defines
#define I2C_SDA 5 // D1 Orange
#define I2C_SCL 4 // D2 Yellow
//#define HW_RESET 12 //TODO
// Debounce interval in ms
//#define DEBOUNCE_INTERVAL 10
//Bounce hwReset {Bounce()};

// Humidity/Temperature/Pressure
#include <Adafruit_Sensor.h>
#include <Adafruit_BME280.h>
#include <Wire.h>

#include <SPI.h>
#include <U8g2lib.h>
U8G2_ST7920_128X64_F_SW_SPI u8g2(U8G2_R0, /* clock E=*/ 14, /* data R/W=*/ 13, /* RS=*/ 15);
byte x {0}; byte y {0};

// Handy timers
#include <SimpleTimer.h>

// SW Serial
#include <SoftwareSerial.h>
SoftwareSerial swSer(0, 2, false, 256); // GPIO15 (TX) and GPIO13 (RX)

// CO2 SERIAL
#define DEBUG_SERIAL Serial
#define SENSOR_SERIAL swSer

byte cmd[9] = {0xFF, 0x01, 0x86, 0x00, 0x00, 0x00, 0x00, 0x00, 0x79};
unsigned char response[7];

// Pressure and temperature
Adafruit_BME280 bme;

// Blynk token
char blynk_token[33] {"7ca0a9293079453499aa5453883510cf"};
char blynk_server[64] {"blynk-cloud.com"};
const uint16_t blynk_port {8442};

// Device Id
char device_id[17] = "Home Weather";
const char fw_ver[17] = "0.1.0";

// Handy timer
SimpleTimer timer;

// Setup Wifi connection
WiFiManager wifiManager;

// Network credentials
String ssid {"YourHomeWeather"};
//String pass {"YHWBopka"}; // пока без пароля

//flag for saving data, flag if connected
bool shouldSaveConfig, connectedFlag = false;

// Sensors data
int t { -100};
int p { -1};
int h { -1};
int co2 { -1};
float tf {0};
float pf {0};
float hf {0};

char loader[4] {'.'};
char dots {':'};

WiFiUDP Udp;
const char* ntpServerName = "ntp1.vniiftri.ru"; //NTP server
const int timeZone = 5;         // GMT +5
unsigned int localPort = 4567;  // local port to listen for UDP packets

const uint8_t custom_font30[358] U8G2_FONT_SECTION("custom_font30") =
  "\14\0\4\5\5\5\5\5\6\22\37\0\0\37\367\37\0\0\0\0\0\1M \6\0\300\210\2\60$\362"
  "CX\303\37\4\231\36*\267\30S\15\21\221\14!\211\20\223\4AM\61\266\234\202I\246\313\17>x"
  "\0\61\21\347cXK\271\330,(\201\206!\244\374\377\17\62$\362CX\3Q\5\21t\14\61\211\20"
  "\262\4\21Q\246e\321\345\372\203\17&'\227\351\362\3\42 y\246\0\63 \362CXCB\317@\22"
  "\305\226iYty\324\24c\313)\17H\321\245N\62]~\360\301\3\64>\362CX\3a\305\20V"
  "\14a\305\20V\14a\305\20V\14a\305\20V\14a\305\20V\14a\305\20V\14a\305\20V\14a"
  "\305\20V\14a\305\20V\14A\316<\2E\243E\227\277\1\0\65!\362CXCB\317@\22\305\226"
  "\351\234\314?\370\200\353\262N\62\275`\202\20E\10I\206\20\204\0\66\32\362CXCB\317@\22\305"
  "\226\351\234\34\271\346\21(\242L\371\301\7\17\67\30\362CX\3Q\15\71\363\10\24Q\246e\321\345"
  "\215;\42\234\374\237\3\70\30\362CXCB\317@\22\305\226\351/\213qGD\246\277\374\340\203\7\71"
  "\32\362CX\303\37\4\231~\371\201\25\220<StY'\231^D\2\315C\12:\11\304A\214\2\365"
  "@P\0\0\0";

static const uint8_t clock_bitmap[] U8X8_PROGMEM= {
  0xF0,0xF3,0xF8,0xF7,0x0C,0xFC,0x8C,0xFC,0x8C,0xFC,0xCC,0xFC,
  0x0C,0xFC,0x3F,0xFC,0x9E,0xF7,0xCC,0xF3
};

void drawMainScreen() {
  u8g2.clearBuffer();
  //draw time
  u8g2.setFont(custom_font30); //30 px height
  //  String timestr = printDigits(hour()) + dots + printDigits(minute());
  String timestr = printDigits(minute()) + dots + printDigits(second());
  u8g2.drawStr(20, 30 , timestr.c_str());
  //update dots
  ((millis() / 1000) % 2) == 0 ? dots = ':' : dots = ' ';
  //wi-fi signal quality
  static uint8_t sig = 0;
  static uint32_t m = millis();
  if ((millis() - m) >1000) {sig++; m = millis();}
  if (sig > 4) sig = 0;
  drawSignalQuality(114, 8, sig);
  u8g2.drawXBMP(0,0,12,10,clock_bitmap);

  //  if (co2 > -1) { // CO2
  //    char co2a [5];
  //    sprintf (co2a, "%i", co2);
  //
  //    u8g2.setFont(u8g2_font_inb19_mf);
  //    x = (128 - u8g2.getStrWidth(co2a)) / 2;
  //    y = u8g2.getAscent() - u8g2.getDescent();
  //    u8g2.drawStr(x, y - 4 , co2a);
  //
  //    const char ppm[] {"ppm CO2"};
  //    u8g2.setFont(u8g2_font_6x12_mf);
  //    x = (128 - u8g2.getStrWidth(ppm)) / 2;
  //    y = y - 4 + u8g2.getAscent() - u8g2.getDescent();
  //    u8g2.drawStr(x, y, ppm);
  //  } else {
  //    loading();
  //    u8g2.setFont(u8g2_font_inb19_mf);
  //    x = (128 - u8g2.getStrWidth(loader)) / 2;
  //    y = u8g2.getAscent() - u8g2.getDescent();
  //    u8g2.drawStr(x, y, loader);
  //  }

  // Cycle Temp, Humidity, Pressure
  String measurementT {"..."};
  String measurementH {"..."};
  String measurementP {"..."};
  const char degree {176};

  if (t > -100) measurementT = "T: " + String(t) + degree + "C";
  if (h > -1) measurementH = "H: " + String(h) + "%";
  if (p > -1) measurementP =  "P: " + String(p) + " mmHg";

  u8g2.setFont(u8g2_font_9x18_mf);
  //  u8g2.drawStr(0, 0, String(WiFi.RSSI()).c_str());
  //  DEBUG_SERIAL.println(WiFi.RSSI());
  //  u8g2.drawStr(0, 0, String(123).c_str());
  //        x = (128 - u8g2.getStrWidth(measurementa))/2;

  char measurementa [12];
  x = 0;
  y = 64 + u8g2.getDescent();
  measurementT.toCharArray(measurementa, 12);
  u8g2.drawStr(0, y, measurementa);

  measurementH.toCharArray(measurementa, 12);
  x = (128 - u8g2.getStrWidth(measurementa));
  u8g2.drawStr(x, y, measurementa);

  y = 46;
  measurementP.toCharArray(measurementa, 12);
  x = (128 - u8g2.getStrWidth(measurementa)) / 2;
  u8g2.drawStr(x, y, measurementa);

  u8g2.sendBuffer();
}

void loading() {
  long unsigned int count {(millis() / 500) % 4};
  memset(loader, '.', count);
  memset(&loader[count], 0, 1);
}

void drawTime() {
  u8g2.clearBuffer();

  //        String timestr = String(hour())+":"+String(minute())+":"+String(second());
  //  updateDots();
  String timestr = printDigits(hour()) + dots + printDigits(minute());
  //        DEBUG_SERIAL.println(timestr);
  u8g2.setFont(u8g2_font_inb30_mf);
  //        u8g2.setFont(u8g2_font_inb30_mn);
  //        u8g2.setFont(u8g2_font_fub35_tn);
  u8g2.drawStr(0, 45 , timestr.c_str());

  u8g2.sendBuffer();
}

// utility for digital clock display: prints preceding colon and leading 0
String printDigits(int digits) {
  String formattedstr = "";
  if (digits < 10) {
    formattedstr = + "0";
  }
  formattedstr = formattedstr + String(digits);
  return formattedstr;
}

void drawBoot(String msg = "Loading...") {
  u8g2.clearBuffer();
  u8g2.setFont(u8g2_font_9x18_mf);
  x = (128 - u8g2.getStrWidth(msg.c_str())) / 2;
  y = 32 + u8g2.getAscent() / 2;
  u8g2.drawStr(x, y, msg.c_str());
  u8g2.sendBuffer();
}
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

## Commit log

2018-01-10 Revert "first"
    This reverts commit 330aa3e9a6a4e5e31f6bceb1ab34fc437067eb4c.
    [homeweather_esp.ino]
2018-01-10 Revert "Revert "first""
    This reverts commit 1f23c698c147afda08bbc08d714f21637b40bdcb.
    [homeweather_esp.ino]
2018-01-26 0.0.3
    adding PWM LED control functionality,
    move fonts and bmp to .h file
2018-02-05 0.0.4
    commit before assembling in case
2018-02-20 0.0.6
    basic button functionality
2018-03-23 0.1.4
    Edit readme
    [FritzingSketch.fzz]
2018-04-09 0.1.12
    added light sensor hysteresis, idle menu exit
2018-04-13 0.1.14
    bugfixes, changed Blynk reconnecting procedure
    [homeweather_esp8266.ino]
2019-05-03 0.1.21
    Arduino JSON 6 support
2019-05-03 0.1.22
    ArduinoJson 6 support
2019-12-06 0.1.23
    SoftwareSerial update fix
    [homeweather_esp8266.ino]
2020-05-15 0.1.24
    fix scheme
    [FritzingSketch.fzz]
2020-05-16 0.1.26
    update readme
    [AlternateFritzingSketch.fzz, FritzingSketch.fzz]
2020-08-23 0.1.28
    add STL files and photos
    [back_cover.stl, case.stl, mount.stl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]
